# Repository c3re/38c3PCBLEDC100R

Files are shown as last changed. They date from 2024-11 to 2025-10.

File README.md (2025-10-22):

# 38c3PCBLEDC100R

The 38c3PCBLEDC100 is a Coaster for your drinks with option for LED and microcontroller upgrade. By stacking the coasters, you can also build nice blinky towers.

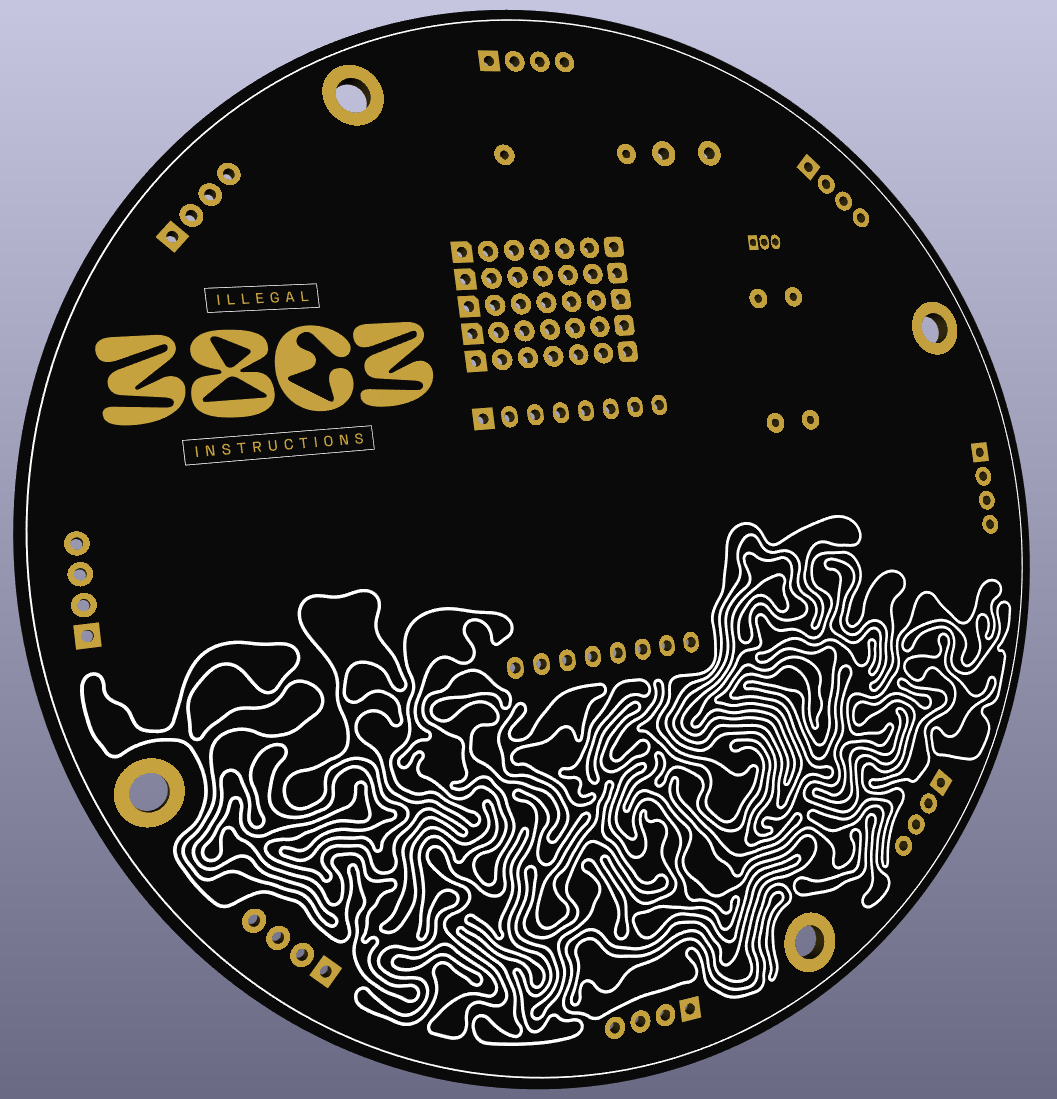
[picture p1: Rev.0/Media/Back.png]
rendering of the 38c3PCBLEDC100R


## Rev.0

### Electrical connections

Important: Do not power the board by USB and an external power supply at the same time!
The Din pin of the first LED is connected to pin D4 (GPIO2) of the Wemos D1 mini. Two of the mounting holes are connected to GND, two of the holes are connected to 5V. You can use this feature to stack multiple 38c3PCBLEDc100R Boards with brass spacers.

## License

The 38c3 Logo and blob was created by Robokid // Luis F. Masallera and Euler Void   
38c3PCBLEDC100R © 2024 by c3RE is licensed under CC BY 4.0. To view a copy of this license,   
visit http://creativecommons.org/licenses/by/4.0/

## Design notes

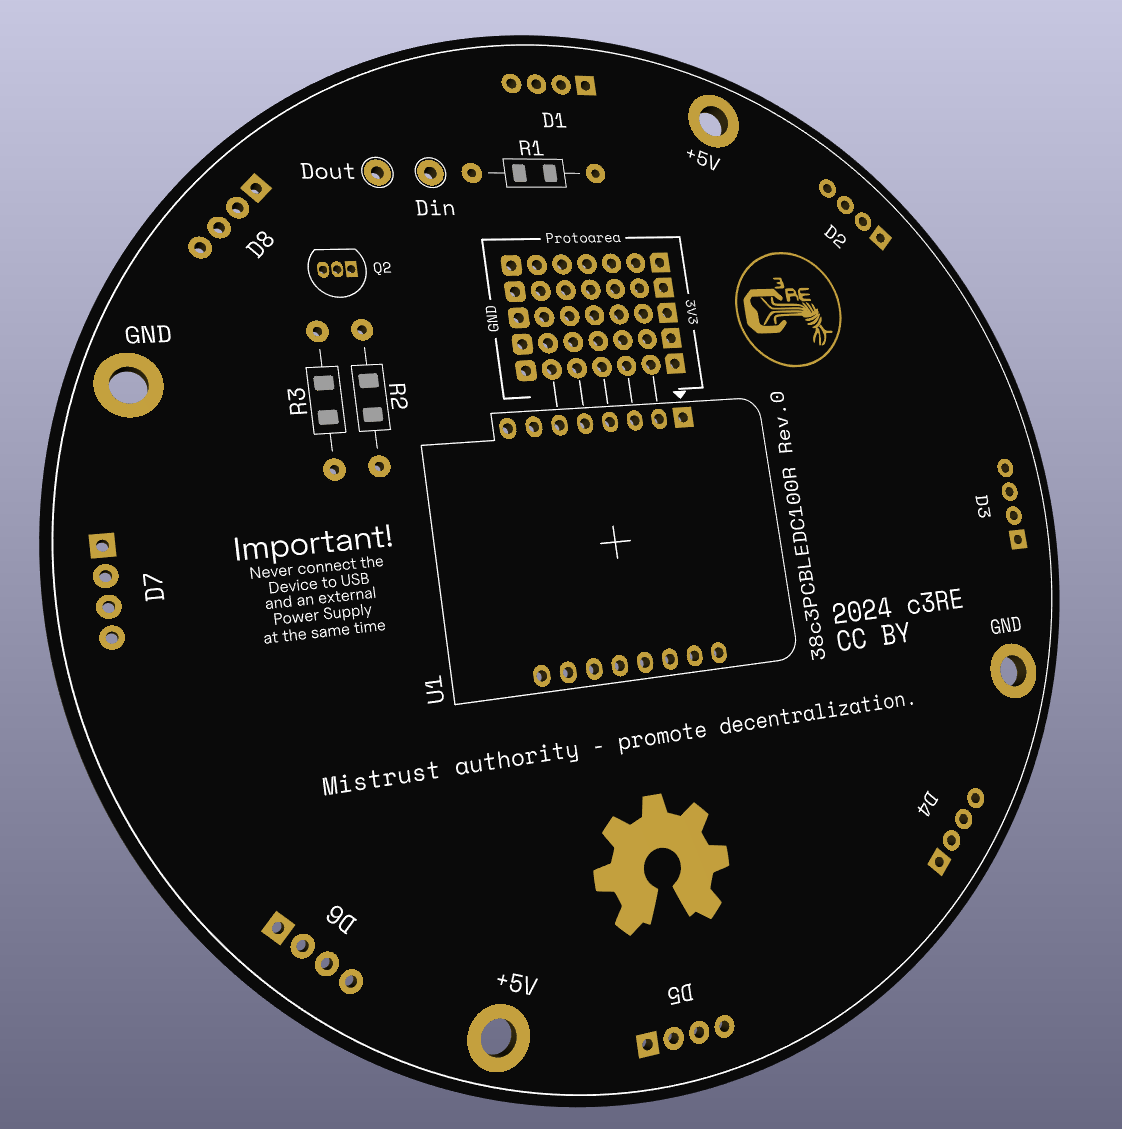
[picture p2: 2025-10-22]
Rev.0/Media/Front.png

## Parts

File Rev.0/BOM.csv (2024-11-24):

Pos. | Qty. | Designator | Description | Manufacturer | Part-No. (Manufacturer) | Vendor | Part-No. (Vendor)
1 | 1 | R1 | Metal Film Resistor 100Ohm 250mW | VICO | MF1/4W-100Ω±1%-OT52 | LCSC | C2903231
2 | 2 | R2-R3 | Metal Film Resistors 10kΩ 250mW | YAGEO | MFR-25FTE52-10K | LCSC | C172967
3 | 1 | Q1 | MOSFET N-CH 100V 320MA TO92-3 | Diodes Inc. | ZVNL110A | DigiKey | ZVNL110A-ND
4 | 8 | D1-D8 | D=5mm RGB LED(Built-in IC) | Worldsemi | WS2812D-F5 | LCSC | C190565
5 | 4 | na | Spacer | Shuntian | M3X25+6 | LCSC | C775782

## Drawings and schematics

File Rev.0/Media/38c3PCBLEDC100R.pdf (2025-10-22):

# C3RE

# Rev.0

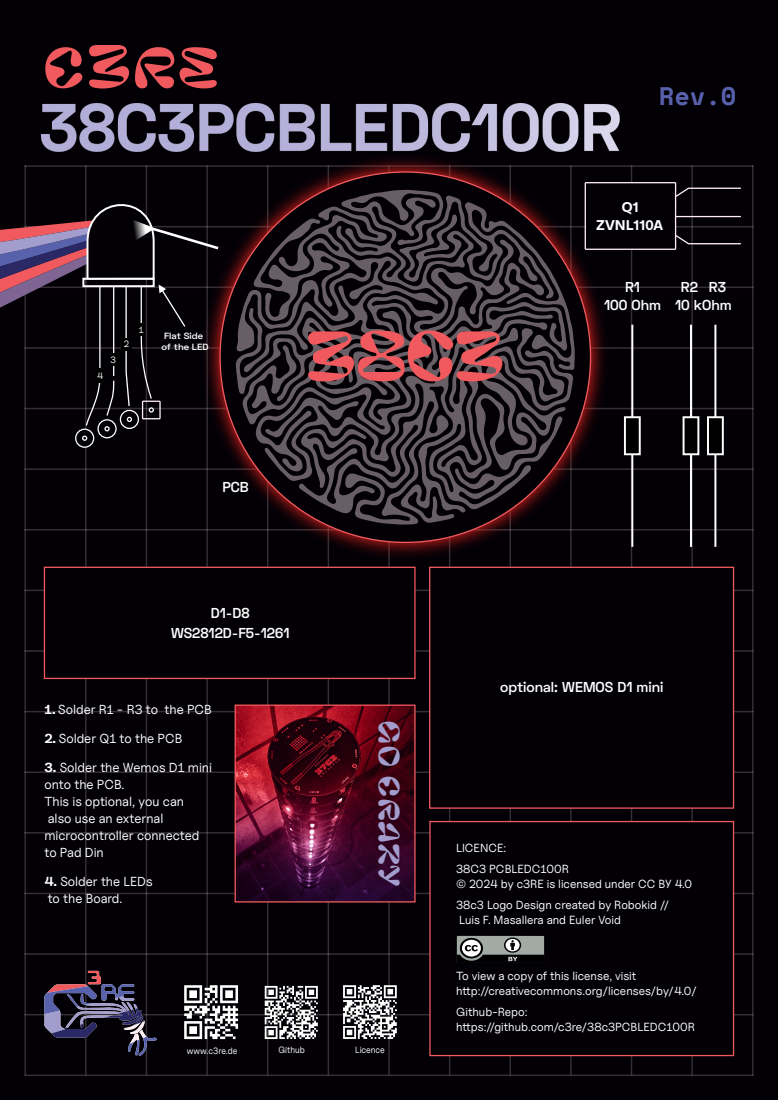
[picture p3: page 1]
PCB

Q1 ZVNL110A

2 | Flat Side of the LED | 100 Ohm | 10 kOhm

1. Solder R1 - R3 to the PCB | | | | | optional: WEMOS D1 | mini

onto the PCB. This is optional, you can also use an external | www.c3re.de | | Github | LicenceGO CRAZY
2. Solder Q1 to the PCB 3. Solder the Wemos D1 mini

microcontroller connected to Pad Din 4. Solder the LEDs | | | | | LICENCE: 38C3 PCBLEDC100R © 2024 by c3RE is licensed under CC BY 4.0

to the Board. | | | | | 38c3 Logo Design created by Robokid // Luis F. Masallera and Euler Void

To view a copy of this license, visit http://creativecommons.org/licenses/by/4.0/Github-Repo:

https://github.com/c3re/38c3PCBLEDC100R

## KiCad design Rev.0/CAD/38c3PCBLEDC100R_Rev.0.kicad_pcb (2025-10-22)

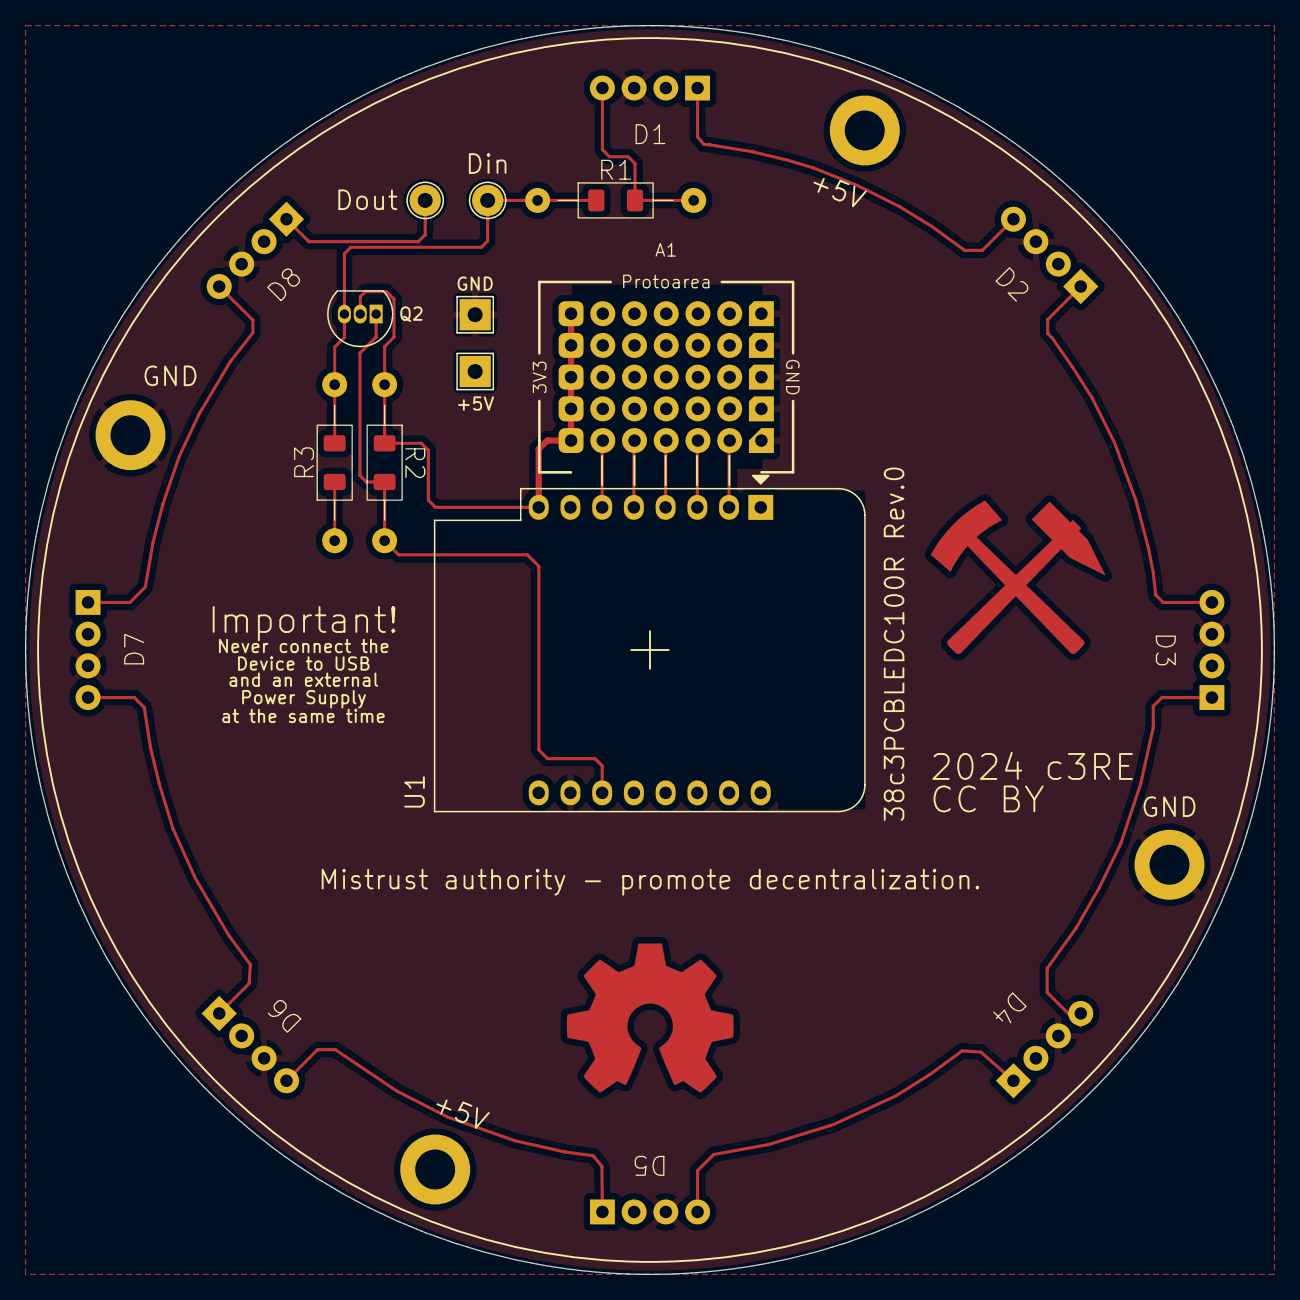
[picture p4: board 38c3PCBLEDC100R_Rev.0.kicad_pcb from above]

Board: 2 copper layers, 100.0 x 100.0 mm, 22 parts (0 on the bottom side), 19 nets.

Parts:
+5V: +5V; MountingHole_3.2mm_M3_DIN965_Pad
+5V#2: +5V; TestPoint_THTPad_2.5x2.5mm_Drill1.2mm
A1: Protoarea
D1, D2, D3, D4, D5, D6, D7, D8: WS2812D-F5; WS2812_THT
Din: Din; TestPoint_THTPad_D2.5mm_Drill1.2mm
Dout: Dout; TestPoint_THTPad_D2.5mm_Drill1.2mm
GND: GND; MountingHole_3.2mm_M3_DIN965_Pad
GND#2: GND; TestPoint_THTPad_2.5x2.5mm_Drill1.2mm
GND#3: GND; MountingHole_3.2mm_M3_DIN965_Pad
H1: +5V; MountingHole_3.2mm_M3_DIN965_Pad
Q2: ZVNL110A; TO-92_Inline
R1: 100; 1206_combi_handsolder
R2, R3: 10k; 1206_combi_handsolder
U1: WeMos_D1_mini; WEMOS_D1_mini_light

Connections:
+5V: +5V.1, +5V#2.1, D1.2 (VCC), D2.2 (VCC), D3.2 (VCC), D4.2 (VCC), D5.2 (VCC), D6.2 (VCC), D7.2 (VCC), D8.2 (VCC), H1.1, R3.1, U1.9 (5V)
/Din: Din.1, Q2.3 (D), R1.1, R3.2
/Dout: D8.1 (DOUT), Dout.1
GND: A1.7 (GND), D1.3 (GND), D2.3 (GND), D3.3 (GND), D4.3 (GND), D5.3 (GND), D6.3 (GND), D7.3 (GND), D8.3 (GND), GND.1, GND#2.1, GND#3.1, U1.10 (GND)
unnamed: A1.8 (Vin), Q2.2 (G), R2.1, U1.8 (3V3)
unnamed: D1.4 (DIN), R1.2
unnamed: D1.1 (DOUT), D2.4 (DIN)
unnamed: D2.1 (DOUT), D3.4 (DIN)
unnamed: D3.1 (DOUT), D4.4 (DIN)
unnamed: D4.1 (DOUT), D5.4 (DIN)
unnamed: D5.1 (DOUT), D6.4 (DIN)
unnamed: D6.1 (DOUT), D7.4 (DIN)
unnamed: D7.1 (DOUT), D8.4 (DIN)
unnamed: Q2.1 (S), R2.2, U1.11 (D4)
unnamed: A1.6, U1.2 (A0)
unnamed: A1.5, U1.3 (D0)
unnamed: A1.3, U1.5 (MISO/D6)
unnamed: A1.2, U1.6 (MOSI/D7)
unnamed: A1.4, U1.4 (SCK/D5)

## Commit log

2024-11-24 Added CAD Files
    [38c3PCBLEDC100R_Rev.0.kicad_pcb, 38c3PCBLEDC100R_Rev.0.kicad_sch]
2024-11-24 BOM added
    [BOM.csv]
2025-10-22 some files added
    [38c3PCBLEDC100R_Rev.0.kicad_pcb, 38c3PCBLEDC100R_Rev.0.kicad_sch]
